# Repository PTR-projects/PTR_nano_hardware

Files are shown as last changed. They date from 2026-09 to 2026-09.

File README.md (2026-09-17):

# KPPTR-hardware

Welcome to the KPPTR-hardware repository! This repository contains the design files for the hardware components used in the KPPTR project. The design files have been created using KiCad 10.0, a powerful open-source electronics design automation suite.

## Project Overview

The design files in this repository correspond to the hardware components that make up the KPPTR project, which enhances the capabilities of DIY amateur rockets and high-altitude balloons. The design files have been crafted using KiCad 10.0, a popular and user-friendly tool for creating electronic schematics and PCB layouts. Both hardware and sofware were developed by PTR member!

## Design Files

The repository includes design files for the various hardware components used in the KPPTR project, including:

- **Schematics**: Detailed electronic schematics that illustrate the connections and components used in the design.
- **PCB Layouts**: PCB layout designs that define the placement and routing of components on the printed circuit board.
- **Libraries**: Custom component libraries and footprints used in the project.

## Getting Started

To access and work with the design files, follow these steps:

1. Clone the repository to your local machine.
2. Install [KiCad 10.0](https://www.kicad.org/download/) if you haven't already.
3. Open the KiCad project files (`.pro` files) in the appropriate subdirectories to access the schematics and PCB layouts.

Feel free to explore the design files and customize them to suit your specific needs. If you make any improvements or modifications to the hardware designs, consider contributing back to the repository to help the community.

## Contributors

- [bartekM](https://gitlab.com/space.tech)
- [https://gitlab.com/andrewziebinski](https://gitlab.com/andrewziebinski)
- [https://gitlab.com/Bdabrowsky](https://gitlab.com/Bdabrowsky)
- [https://gitlab.com/krecik1](https://gitlab.com/krecik1)
- [https://gitlab.com/US_air_force](https://gitlab.com/US_air_force)
- [https://gitlab.com/karmelek96](https://gitlab.com/karmelek96)
- and many others!

## License

This project is licensed under the [MIT License](LICENSE). You can freely use, modify, and distribute the code in accordance with the terms of the license.

Unless required by applicable law or agreed to in writing, this
software is distributed on an "AS IS" BASIS, WITHOUT WARRANTIES OR
CONDITIONS OF ANY KIND, either express or implied.

Thank you for your interest in KPPTR-firmware! If you have any questions or feedback, please don't hesitate to reach out to us. Happy coding and safe flights!

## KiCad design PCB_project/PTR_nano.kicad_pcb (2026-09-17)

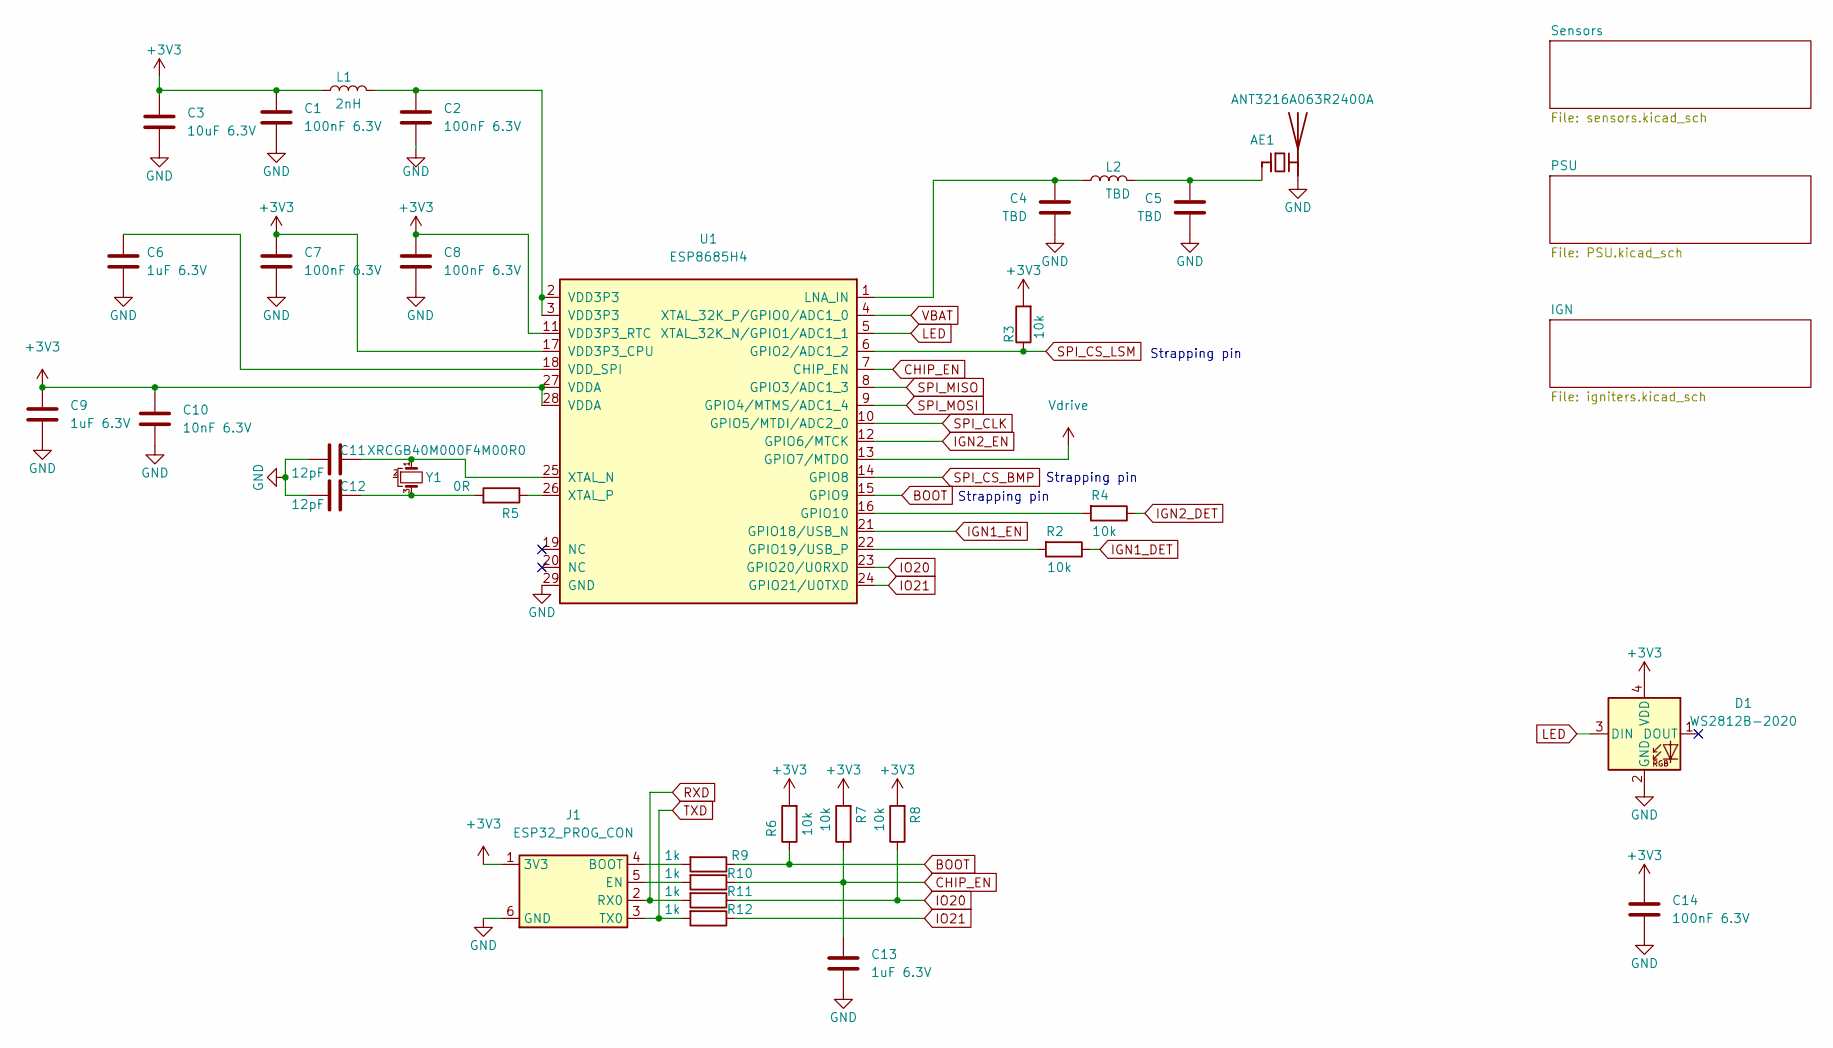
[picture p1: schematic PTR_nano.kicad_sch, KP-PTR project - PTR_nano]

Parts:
AE1: ANT3216A063R2400A
C1, C2, C7, C8, C14: 100nF 6.3V; C_0201_0603Metric
C3: 10uF 6.3V; C_0402_1005Metric
C4, C5: TBD; C_0201_0603Metric
C6, C9, C13: 1uF 6.3V; C_0201_0603Metric
C10: 10nF 6.3V; C_0201_0603Metric
C11, C12: 12pF; C_0201_0603Metric
D1: WS2812B-2020
J1: ESP32_PROG_CON; PinHeader_1x06_P1.27mm_Vertical
L1: 2nH; L_0201_0603Metric
L2: TBD; L_0201_0603Metric
R2, R3, R4, R6, R7, R8: 10k; R_0201_0603Metric
R5: 0R; R_0201_0603Metric
R9, R10, R11, R12: 1k; R_0201_0603Metric
U1: ESP8685H4; ESP8685; PARTREV 2.0
Y1: XRCGB40M000F4M00R0; Crystal_SMD_1612-4Pin_1.6x1.2mm

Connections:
+3V3: C1.1, C3.1, C7.1, C8.1, C9.1, C10.1, C14.1, D1.4 (VDD), J1.1 (3V3), L1.1, R3.2, R6.2, R7.2, R8.2, U1.11 (VDD3P3_RTC), U1.17 (VDD3P3_CPU), U1.27 (VDDA), U1.28 (VDDA); also elsewhere on the board
BOOT: R6.1, R9.1, U1.15 (GPIO9)
CHIP_EN: C13.1, R7.1, R10.1, U1.7 (CHIP_EN)
GND: AE1.2 (PCB_Trace), C1.2, C2.2, C3.2, C4.2, C5.2, C6.2, C7.2, C8.2, C9.2, C10.2, C11.1, C12.1, C13.2, C14.2, D1.2 (GND), J1.6 (GND), U1.29 (GND); also elsewhere on the board
IGN1_DET: R2.1; also elsewhere on the board
IGN1_EN: U1.21 (GPIO18/USB_N); also elsewhere on the board
IGN2_DET: R4.1; also elsewhere on the board
IGN2_EN: U1.12 (GPIO6/MTCK); also elsewhere on the board
IO20: R8.1, R11.1, U1.23 (GPIO20/U0RXD)
IO21: R12.1, U1.24 (GPIO21/U0TXD)
LED: D1.3 (DIN), U1.5 (XTAL_32K_N/GPIO1/ADC1_1)
unnamed: AE1.1 (FEED), C5.1, L2.1
unnamed: C2.1, L1.2, U1.2 (VDD3P3), U1.3 (VDD3P3)
unnamed: C4.1, L2.2, U1.1 (LNA_IN)
unnamed: C6.1, U1.18 (VDD_SPI)
unnamed: C11.2, U1.25 (XTAL_N), Y1.1
unnamed: C12.2, R5.2, Y1.3
unnamed: J1.4 (BOOT), R9.2
unnamed: J1.5 (EN), R10.2
unnamed: R2.2, U1.22 (GPIO19/USB_P)
unnamed: R4.2, U1.16 (GPIO10)
unnamed: R5.1, U1.26 (XTAL_P)
RXD: J1.2 (RX0), R11.2
SPI_CLK: U1.10 (GPIO5/MTDI/ADC2_0); also elsewhere on the board
SPI_CS_BMP: U1.14 (GPIO8); also elsewhere on the board
SPI_CS_LSM: R3.1, U1.6 (GPIO2/ADC1_2); also elsewhere on the board
SPI_MISO: U1.8 (GPIO3/ADC1_3); also elsewhere on the board
SPI_MOSI: U1.9 (GPIO4/MTMS/ADC1_4); also elsewhere on the board
TXD: J1.3 (TX0), R12.2
VBAT: U1.4 (XTAL_32K_P/GPIO0/ADC1_0); also elsewhere on the board
Vdrive: U1.13 (GPIO7/MTDO); also elsewhere on the board

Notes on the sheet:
Strapping pin

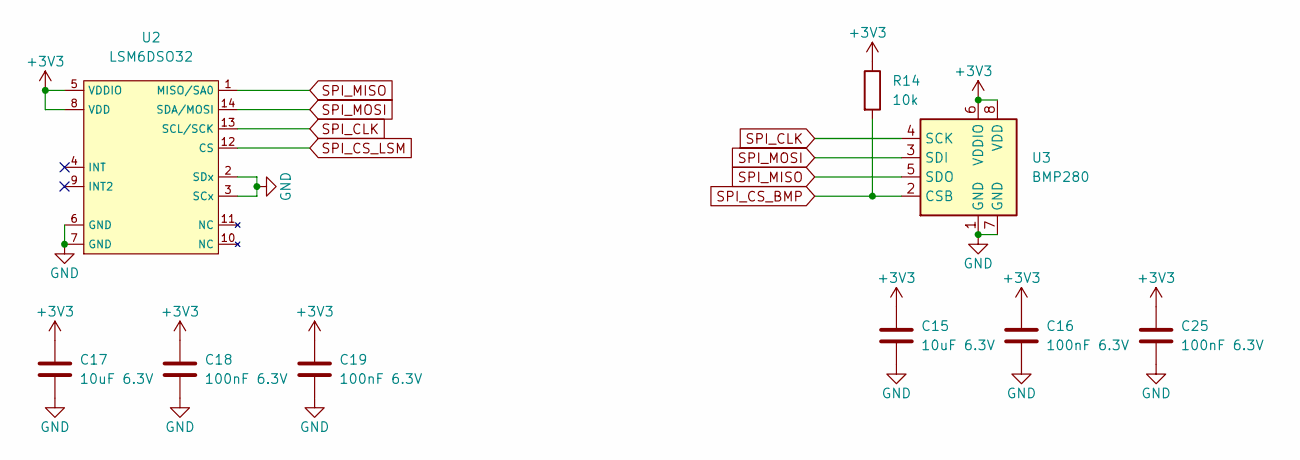
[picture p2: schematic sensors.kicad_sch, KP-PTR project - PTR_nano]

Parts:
C15, C17: 10uF 6.3V; C_0402_1005Metric
C16, C18, C19, C25: 100nF 6.3V; C_0201_0603Metric
R14: 10k; R_0201_0603Metric
U2: LSM6DSO32
U3: BMP280; Bosch_LGA-8_2x2.5mm_P0.65mm_ClockwisePinNumbering

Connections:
+3V3: C15.1, C16.1, C17.1, C18.1, C19.1, C25.1, R14.1, U2.5 (VDDIO), U2.8 (VDD), U3.6 (VDDIO), U3.8 (VDD); also elsewhere on the board
GND: C15.2, C16.2, C17.2, C18.2, C19.2, C25.2, U2.2 (SDx), U2.3 (SCx), U2.6 (GND), U2.7 (GND), U3.1 (GND), U3.7 (GND); also elsewhere on the board
SPI_CLK: U2.13 (SCL/SCK), U3.4 (SCK); also elsewhere on the board
SPI_CS_BMP: R14.2, U3.2 (CSB); also elsewhere on the board
SPI_CS_LSM: U2.12 (CS); also elsewhere on the board
SPI_MISO: U2.1 (MISO/SA0), U3.5 (SDO); also elsewhere on the board
SPI_MOSI: U2.14 (SDA/MOSI), U3.3 (SDI); also elsewhere on the board

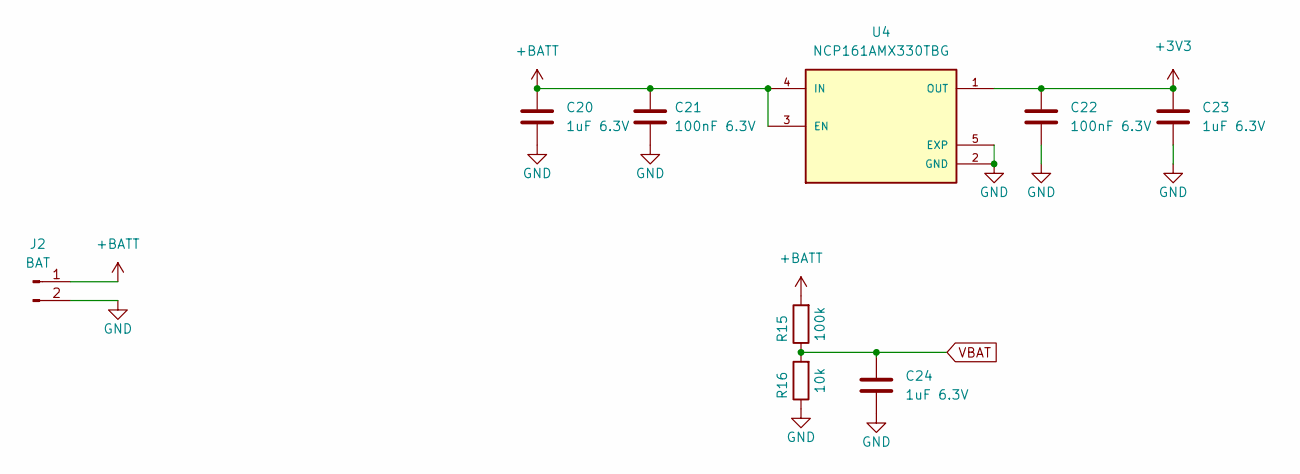
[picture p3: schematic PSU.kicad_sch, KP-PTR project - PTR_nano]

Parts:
C20, C23, C24: 1uF 6.3V; C_0201_0603Metric
C21, C22: 100nF 6.3V; C_0201_0603Metric
J2: BAT; Micro IGN-BAT pads
R15: 100k; R_0201_0603Metric
R16: 10k; R_0201_0603Metric
U4: NCP161AMX330TBG; PARTREV A

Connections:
+3V3: C22.1, C23.1, U4.1 (OUT); also elsewhere on the board
+BATT: C20.1, C21.1, J2.1, R15.2, U4.3 (EN), U4.4 (IN); also elsewhere on the board
GND: C20.2, C21.2, C22.2, C23.2, C24.2, J2.2, R16.1, U4.2 (GND), U4.5 (EXP); also elsewhere on the board
VBAT: C24.1, R15.1, R16.2; also elsewhere on the board

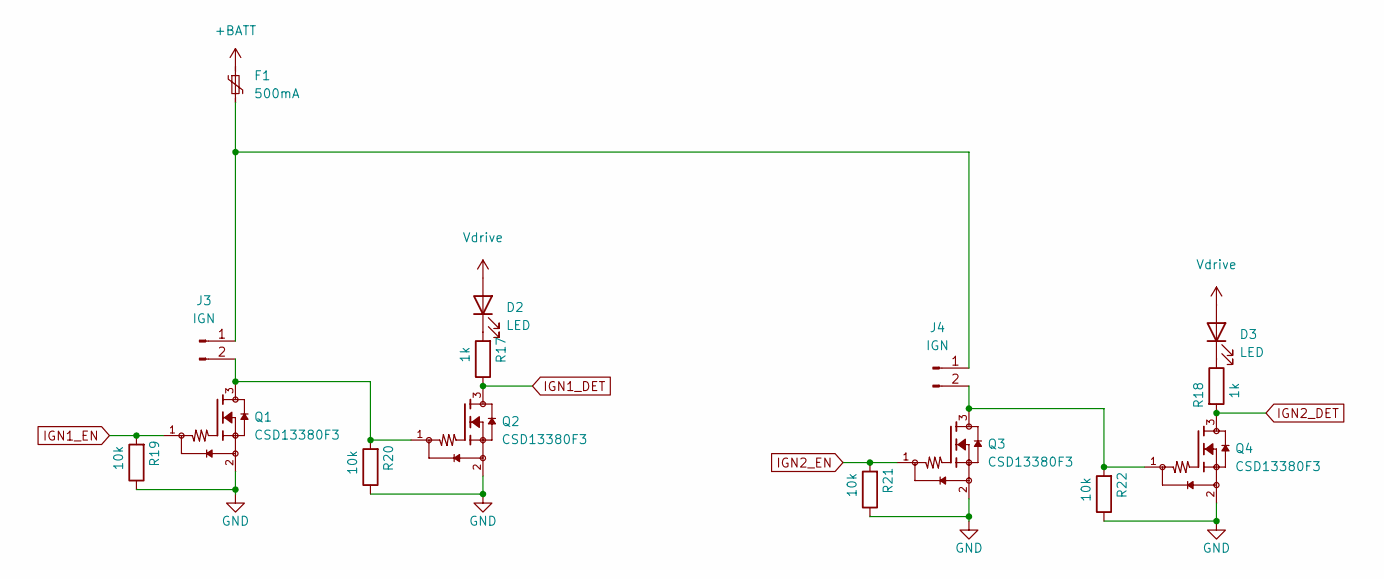
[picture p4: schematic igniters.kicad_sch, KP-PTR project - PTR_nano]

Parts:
D2, D3: LED; LED_0402_1005Metric
F1: 500mA; Fuse_0805_2012Metric
J3, J4: IGN; Micro IGN-BAT pads
Q1, Q2, Q3, Q4: CSD13380F3; PARTREV October 2016
R17, R18: 1k; R_0201_0603Metric
R19, R20, R21, R22: 10k; R_0201_0603Metric

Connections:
+BATT: F1.1; also elsewhere on the board
GND: Q1.2, Q2.2, Q3.2, Q4.2, R19.1, R20.1, R21.1, R22.1; also elsewhere on the board
IGN1_DET: Q2.3, R17.1; also elsewhere on the board
IGN1_EN: Q1.1, R19.2; also elsewhere on the board
IGN2_DET: Q4.3, R18.2; also elsewhere on the board
IGN2_EN: Q3.1, R21.2; also elsewhere on the board
unnamed: D2.1 (K), R17.2
unnamed: D3.1 (K), R18.1
unnamed: F1.2, J3.1, J4.1
unnamed: J3.2, Q1.3, Q2.1, R20.2
unnamed: J4.2, Q3.3, Q4.1, R22.2
Vdrive: D2.2 (A), D3.2 (A); also elsewhere on the board

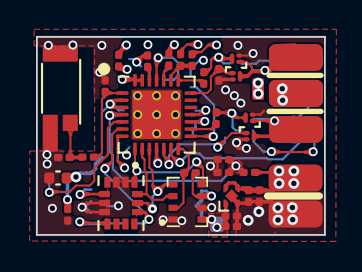
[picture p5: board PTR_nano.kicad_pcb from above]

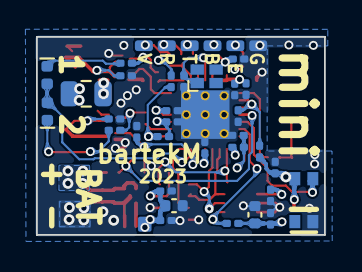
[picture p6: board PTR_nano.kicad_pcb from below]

Board: 6 copper layers, 16.0 x 11.0 mm, 65 parts (31 on the bottom side), 37 nets.

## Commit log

2026-09-17 Archive version of the project
    [PSU.kicad_sch, PTR_nano.kicad_pcb, PTR_nano.kicad_sch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]
2026-09-21 Board name fix
2026-09-30 Project renamed to PTR-nano-pcb
2026-10-06 Pressure sensor changed to BMP581
    + library fixed
